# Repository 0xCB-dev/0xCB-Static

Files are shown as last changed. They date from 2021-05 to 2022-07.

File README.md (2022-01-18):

# 0xcb-static
## 40% with OLED and Encoder running QMK

Licence | OSHWA
:-------------------------:|:-------------------------:
 | (https://certification.oshwa.org/de000114.html)

#### Flashing

* `qmk clone`
* `cd qmk_firmware`
* `export LTO=Y`
* To go to bootloader hold the ESC key while plugging in (or RESET switch, then hold the BOOT switch, release RESET, release BOOT).
The board should now appear in lsusb (or device manager).
* `make 0xcb/static:via:flash`

### Assembly:

You can use the [humanpnp](https://files.0xcb.dev/0xCB-Static/humanpnp.html) to easily place components.

### PCB:
KiCad 6 stable

[Schematic](https://github.com/0xCB-dev/0xcb-static/blob/main/rev1.0/0xcb-static.pdf)

Top | Bottom
:-------------------------:|:-------------------------:
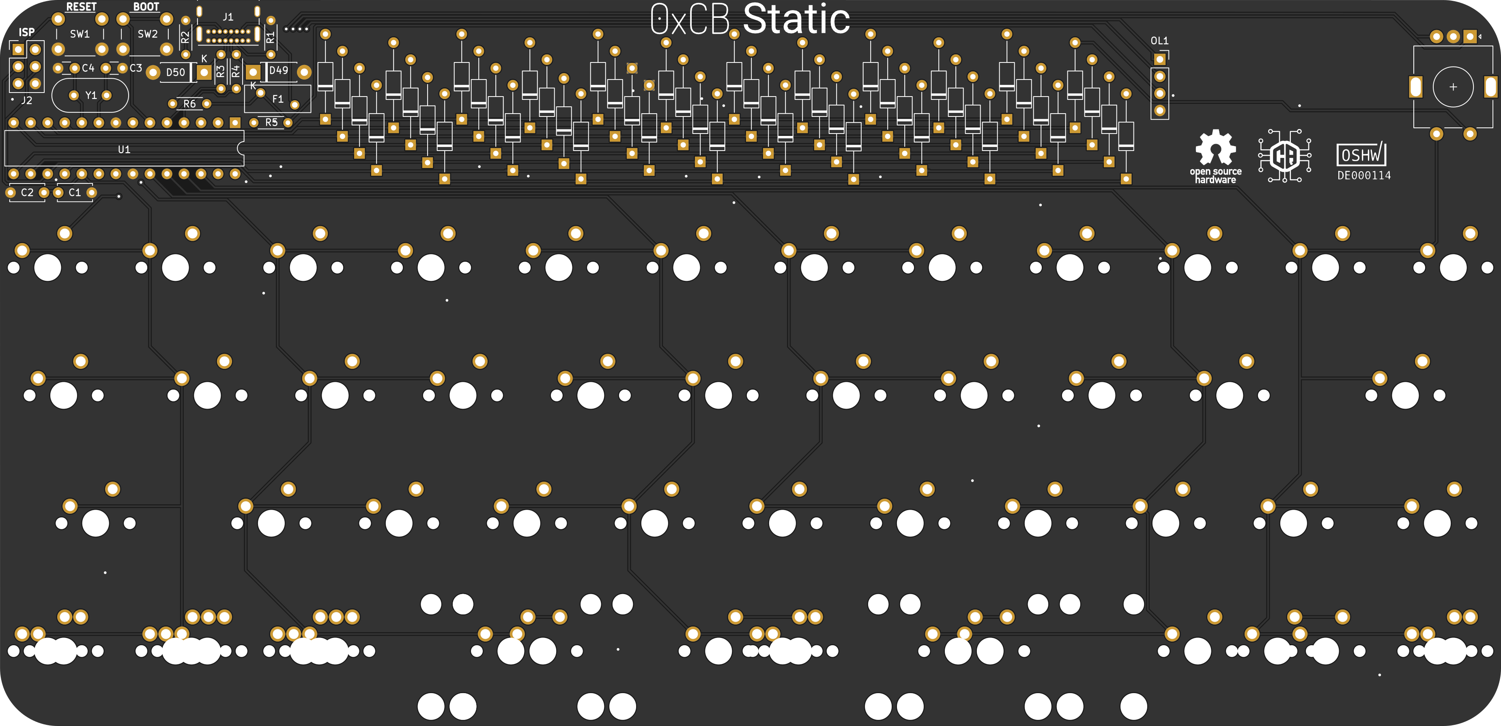
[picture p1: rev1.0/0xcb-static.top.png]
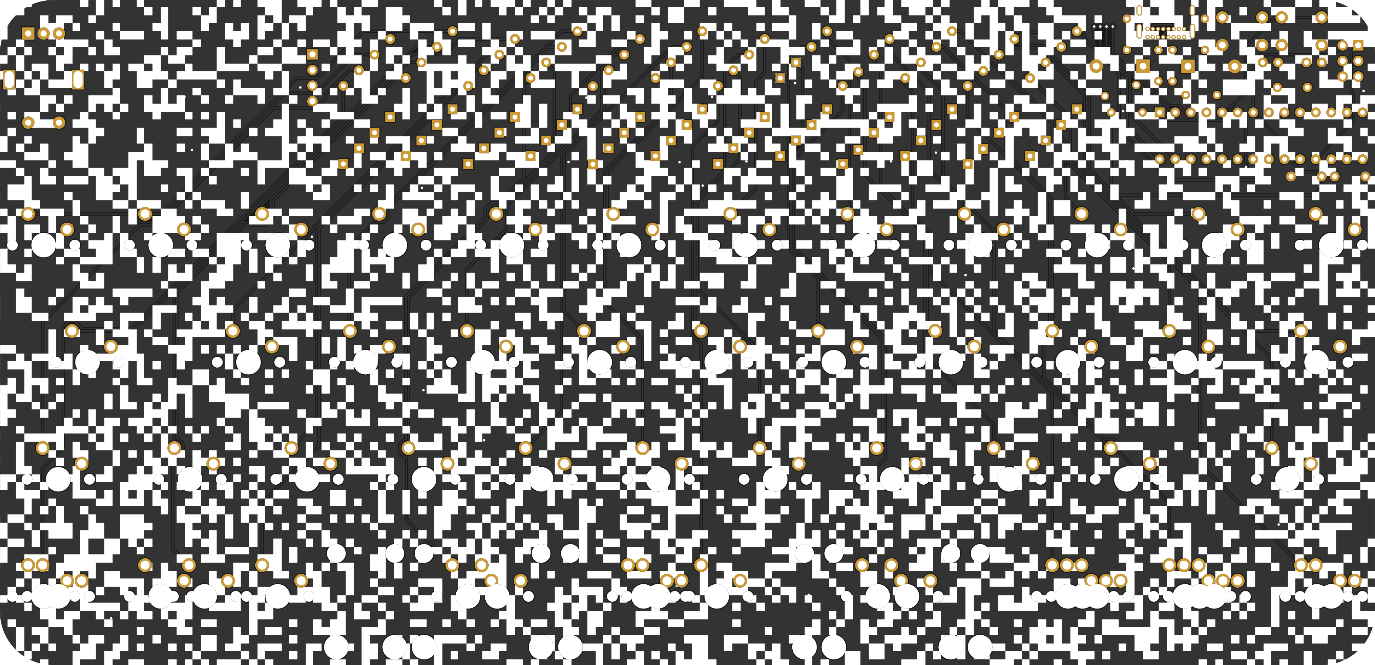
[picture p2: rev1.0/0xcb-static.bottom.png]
  |  

### 3D files:
[STLs](https://github.com/0xCB-dev/0xcb-static/tree/main/3D-files)

#### BOM:
| References | Value | Quantity |Part Nb. |
|---|---|---|---|
| C3, C4 | 20pF | 2 |C415398 |
| C1, C2 | 0.1uF | 2 |C409821 |
| R1, R2 | 5.1K | 2 |C58676 |
| R3, R4 | 75 | 2 |C713897 |
| R5 | 10k | 1 |C58673 |
| R6 | 1.5k | 1 |C433494 |
| D1, ..., D48 | 1N4148 | 48 |C14516 |
| D49, D50 | 1N4729 | 2 |C2532 |
| U1 | ATmega328-P | 1 |ATMEGA328P-PU-ND |
| Y1 | 16MHz | 1 |C16212 |
| F1 | 500mA | 1 |C268799 |
| SW1, SW2 | RESET, BOOT | 1 |450-1650-ND |
| MX1, ..., MX44 | MX-NoLED | 43 |Cherry MX switches |
| OL1 | OLED | 1 |SSD1306 128x32 |
| MX12 | EC11 | 1 |PEC11R-4220F-S0024-ND|
| J1 | USB4085 Type C | 1 |640-USB4085-GF-A |

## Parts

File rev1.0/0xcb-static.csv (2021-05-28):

Source: | /home/conor/Sites/0xcb-static/PCB/rev1.0/0xcb-static.kicad_sch
Date: | Fr 28 Mai 2021 11:54:58 CEST
Tool: | Eeschema (5.99.0-10540-g55c1d814f9)
Generator: | /usr/share/kicad-nightly/plugins/bom_csv_grouped_by_value.py
Component Count: | 111
Individual Components:
Item | Qty | Reference(s) | Value | LibPart | Footprint | Datasheet | Part Nb.
 |  | C1 | 0.1uF | Device:C_Small | Capacitor_THT:C_Disc_D5.0mm_W2.5mm_P5.00mm | ~ | C277965
 |  | C2 | 0.1uF | Device:C_Small | Capacitor_THT:C_Disc_D5.0mm_W2.5mm_P5.00mm | ~ | C277965
 |  | C3 | 20pF | Device:C_Small | Capacitor_THT:C_Disc_D3.0mm_W1.6mm_P2.50mm | ~ | C254096
 |  | C4 | 20pF | Device:C_Small | Capacitor_THT:C_Disc_D3.0mm_W1.6mm_P2.50mm | ~ | C254096
 |  | D1 | 1N4148 | Diode:1N4148 | Diode_THT:D_DO-35_SOD27_P12.70mm_Horizontal | https://assets.nexperia.com/documents/data-sheet/1N4148_1N4448.pdf | C14538
 |  | D2 | 1N4148 | Diode:1N4148 | Diode_THT:D_DO-35_SOD27_P12.70mm_Horizontal | https://assets.nexperia.com/documents/data-sheet/1N4148_1N4448.pdf | C14538
 |  | D3 | 1N4148 | Diode:1N4148 | Diode_THT:D_DO-35_SOD27_P12.70mm_Horizontal | https://assets.nexperia.com/documents/data-sheet/1N4148_1N4448.pdf | C14538
 |  | D4 | 1N4148 | Diode:1N4148 | Diode_THT:D_DO-35_SOD27_P12.70mm_Horizontal | https://assets.nexperia.com/documents/data-sheet/1N4148_1N4448.pdf | C14538
 |  | D5 | 1N4148 | Diode:1N4148 | Diode_THT:D_DO-35_SOD27_P12.70mm_Horizontal | https://assets.nexperia.com/documents/data-sheet/1N4148_1N4448.pdf | C14538
 |  | D6 | 1N4148 | Diode:1N4148 | Diode_THT:D_DO-35_SOD27_P12.70mm_Horizontal | https://assets.nexperia.com/documents/data-sheet/1N4148_1N4448.pdf | C14538
 |  | D7 | 1N4148 | Diode:1N4148 | Diode_THT:D_DO-35_SOD27_P12.70mm_Horizontal | https://assets.nexperia.com/documents/data-sheet/1N4148_1N4448.pdf | C14538
 |  | D8 | 1N4148 | Diode:1N4148 | Diode_THT:D_DO-35_SOD27_P12.70mm_Horizontal | https://assets.nexperia.com/documents/data-sheet/1N4148_1N4448.pdf | C14538
 |  | D9 | 1N4148 | Diode:1N4148 | Diode_THT:D_DO-35_SOD27_P12.70mm_Horizontal | https://assets.nexperia.com/documents/data-sheet/1N4148_1N4448.pdf | C14538
 |  | D10 | 1N4148 | Diode:1N4148 | Diode_THT:D_DO-35_SOD27_P12.70mm_Horizontal | https://assets.nexperia.com/documents/data-sheet/1N4148_1N4448.pdf | C14538
 |  | D11 | 1N4148 | Diode:1N4148 | Diode_THT:D_DO-35_SOD27_P12.70mm_Horizontal | https://assets.nexperia.com/documents/data-sheet/1N4148_1N4448.pdf | C14538
 |  | D12 | 1N4148 | Diode:1N4148 | Diode_THT:D_DO-35_SOD27_P12.70mm_Horizontal | https://assets.nexperia.com/documents/data-sheet/1N4148_1N4448.pdf | C14538
 |  | D13 | 1N4148 | Diode:1N4148 | Diode_THT:D_DO-35_SOD27_P12.70mm_Horizontal | https://assets.nexperia.com/documents/data-sheet/1N4148_1N4448.pdf | C14538
 |  | D14 | 1N4148 | Diode:1N4148 | Diode_THT:D_DO-35_SOD27_P12.70mm_Horizontal | https://assets.nexperia.com/documents/data-sheet/1N4148_1N4448.pdf | C14538
 |  | D15 | 1N4148 | Diode:1N4148 | Diode_THT:D_DO-35_SOD27_P12.70mm_Horizontal | https://assets.nexperia.com/documents/data-sheet/1N4148_1N4448.pdf | C14538
 |  | D16 | 1N4148 | Diode:1N4148 | Diode_THT:D_DO-35_SOD27_P12.70mm_Horizontal | https://assets.nexperia.com/documents/data-sheet/1N4148_1N4448.pdf | C14538
 |  | D17 | 1N4148 | Diode:1N4148 | Diode_THT:D_DO-35_SOD27_P12.70mm_Horizontal | https://assets.nexperia.com/documents/data-sheet/1N4148_1N4448.pdf | C14538
 |  | D18 | 1N4148 | Diode:1N4148 | Diode_THT:D_DO-35_SOD27_P12.70mm_Horizontal | https://assets.nexperia.com/documents/data-sheet/1N4148_1N4448.pdf | C14538
 |  | D19 | 1N4148 | Diode:1N4148 | Diode_THT:D_DO-35_SOD27_P12.70mm_Horizontal | https://assets.nexperia.com/documents/data-sheet/1N4148_1N4448.pdf | C14538
 |  | D20 | 1N4148 | Diode:1N4148 | Diode_THT:D_DO-35_SOD27_P12.70mm_Horizontal | https://assets.nexperia.com/documents/data-sheet/1N4148_1N4448.pdf | C14538
 |  | D21 | 1N4148 | Diode:1N4148 | Diode_THT:D_DO-35_SOD27_P12.70mm_Horizontal | https://assets.nexperia.com/documents/data-sheet/1N4148_1N4448.pdf | C14538
 |  | D22 | 1N4148 | Diode:1N4148 | Diode_THT:D_DO-35_SOD27_P12.70mm_Horizontal | https://assets.nexperia.com/documents/data-sheet/1N4148_1N4448.pdf | C14538
 |  | D23 | 1N4148 | Diode:1N4148 | Diode_THT:D_DO-35_SOD27_P12.70mm_Horizontal | https://assets.nexperia.com/documents/data-sheet/1N4148_1N4448.pdf | C14538
 |  | D24 | 1N4148 | Diode:1N4148 | Diode_THT:D_DO-35_SOD27_P12.70mm_Horizontal | https://assets.nexperia.com/documents/data-sheet/1N4148_1N4448.pdf | C14538
 |  | D25 | 1N4148 | Diode:1N4148 | Diode_THT:D_DO-35_SOD27_P12.70mm_Horizontal | https://assets.nexperia.com/documents/data-sheet/1N4148_1N4448.pdf | C14538
 |  | D26 | 1N4148 | Diode:1N4148 | Diode_THT:D_DO-35_SOD27_P12.70mm_Horizontal | https://assets.nexperia.com/documents/data-sheet/1N4148_1N4448.pdf | C14538
 |  | D27 | 1N4148 | Diode:1N4148 | Diode_THT:D_DO-35_SOD27_P12.70mm_Horizontal | https://assets.nexperia.com/documents/data-sheet/1N4148_1N4448.pdf | C14538
 |  | D28 | 1N4148 | Diode:1N4148 | Diode_THT:D_DO-35_SOD27_P12.70mm_Horizontal | https://assets.nexperia.com/documents/data-sheet/1N4148_1N4448.pdf | C14538
 |  | D29 | 1N4148 | Diode:1N4148 | Diode_THT:D_DO-35_SOD27_P12.70mm_Horizontal | https://assets.nexperia.com/documents/data-sheet/1N4148_1N4448.pdf | C14538
 |  | D30 | 1N4148 | Diode:1N4148 | Diode_THT:D_DO-35_SOD27_P12.70mm_Horizontal | https://assets.nexperia.com/documents/data-sheet/1N4148_1N4448.pdf | C14538
 |  | D31 | 1N4148 | Diode:1N4148 | Diode_THT:D_DO-35_SOD27_P12.70mm_Horizontal | https://assets.nexperia.com/documents/data-sheet/1N4148_1N4448.pdf | C14538
 |  | D32 | 1N4148 | Diode:1N4148 | Diode_THT:D_DO-35_SOD27_P12.70mm_Horizontal | https://assets.nexperia.com/documents/data-sheet/1N4148_1N4448.pdf | C14538
 |  | D33 | 1N4148 | Diode:1N4148 | Diode_THT:D_DO-35_SOD27_P12.70mm_Horizontal | https://assets.nexperia.com/documents/data-sheet/1N4148_1N4448.pdf | C14538
 |  | D34 | 1N4148 | Diode:1N4148 | Diode_THT:D_DO-35_SOD27_P12.70mm_Horizontal | https://assets.nexperia.com/documents/data-sheet/1N4148_1N4448.pdf | C14538
 |  | D35 | 1N4148 | Diode:1N4148 | Diode_THT:D_DO-35_SOD27_P12.70mm_Horizontal | https://assets.nexperia.com/documents/data-sheet/1N4148_1N4448.pdf | C14538
 |  | D36 | 1N4148 | Diode:1N4148 | Diode_THT:D_DO-35_SOD27_P12.70mm_Horizontal | https://assets.nexperia.com/documents/data-sheet/1N4148_1N4448.pdf | C14538
 |  | D37 | 1N4148 | Diode:1N4148 | Diode_THT:D_DO-35_SOD27_P12.70mm_Horizontal | https://assets.nexperia.com/documents/data-sheet/1N4148_1N4448.pdf | C14538
 |  | D38 | 1N4148 | Diode:1N4148 | Diode_THT:D_DO-35_SOD27_P12.70mm_Horizontal | https://assets.nexperia.com/documents/data-sheet/1N4148_1N4448.pdf | C14538
 |  | D39 | 1N4148 | Diode:1N4148 | Diode_THT:D_DO-35_SOD27_P12.70mm_Horizontal | https://assets.nexperia.com/documents/data-sheet/1N4148_1N4448.pdf | C14538
 |  | D40 | 1N4148 | Diode:1N4148 | Diode_THT:D_DO-35_SOD27_P12.70mm_Horizontal | https://assets.nexperia.com/documents/data-sheet/1N4148_1N4448.pdf | C14538
 |  | D41 | 1N4148 | Diode:1N4148 | Diode_THT:D_DO-35_SOD27_P12.70mm_Horizontal | https://assets.nexperia.com/documents/data-sheet/1N4148_1N4448.pdf | C14538
 |  | D42 | 1N4148 | Diode:1N4148 | Diode_THT:D_DO-35_SOD27_P12.70mm_Horizontal | https://assets.nexperia.com/documents/data-sheet/1N4148_1N4448.pdf | C14538
 |  | D43 | 1N4148 | Diode:1N4148 | Diode_THT:D_DO-35_SOD27_P12.70mm_Horizontal | https://assets.nexperia.com/documents/data-sheet/1N4148_1N4448.pdf | C14538
 |  | D44 | 1N4148 | Diode:1N4148 | Diode_THT:D_DO-35_SOD27_P12.70mm_Horizontal | https://assets.nexperia.com/documents/data-sheet/1N4148_1N4448.pdf | C14538
 |  | D45 | 1N4148 | Diode:1N4148 | Diode_THT:D_DO-35_SOD27_P12.70mm_Horizontal | https://assets.nexperia.com/documents/data-sheet/1N4148_1N4448.pdf | C14538
 |  | D46 | 1N4729 | Device:D_Schottky | Diode_THT:D_DO-41_SOD81_P7.62mm_Horizontal | ~ | C2532
 |  | D47 | 1N4729 | Device:D_Schottky | Diode_THT:D_DO-41_SOD81_P7.62mm_Horizontal | ~ | C2532
 |  | D48 | 1N4148 | Diode:1N4148 | Diode_THT:D_DO-35_SOD27_P12.70mm_Horizontal | https://assets.nexperia.com/documents/data-sheet/1N4148_1N4448.pdf | C14538
 |  | D49 | 1N4148 | Diode:1N4148 | Diode_THT:D_DO-35_SOD27_P12.70mm_Horizontal | https://assets.nexperia.com/documents/data-sheet/1N4148_1N4448.pdf | C14538
 |  | D50 | 1N4148 | Diode:1N4148 | Diode_THT:D_DO-35_SOD27_P12.70mm_Horizontal | https://assets.nexperia.com/documents/data-sheet/1N4148_1N4448.pdf | C14538
 |  | F1 | 500mA | Device:Polyfuse_Small | Fuse:Fuse_BelFuse_0ZRE0025FF_L9.6mm_W3.8mm | ~ | C268799
 |  | J1 | USB_C_Receptacle_USB2.0 | Connector:USB_C_Receptacle_USB2.0 | Connector_USB:USB_C_Receptacle_GCT_USB4085 | https://www.usb.org/sites/default/files/documents/usb_type-c.zip | 2073-USB4085-GF-ACT-ND
 |  | MX1 | MX-NoLED | static:MX-NoLED | MX_Only:MXOnly-1U-NoLED |  | amz
 |  | MX2 | MX-NoLED | static:MX-NoLED | MX_Only:MXOnly-1U-NoLED |  | amz
 |  | MX3 | MX-NoLED | static:MX-NoLED | MX_Only:MXOnly-1U-NoLED |  | amz
 |  | MX4 | MX-NoLED | static:MX-NoLED | MX_Only:MXOnly-1U-NoLED |  | amz
 |  | MX5 | MX-NoLED | static:MX-NoLED | MX_Only:MXOnly-1U-NoLED |  | amz
 |  | MX6 | MX-NoLED | static:MX-NoLED | MX_Only:MXOnly-1U-NoLED |  | amz
 |  | MX7 | MX-NoLED | static:MX-NoLED | MX_Only:MXOnly-1U-NoLED |  | amz
 |  | MX8 | MX-NoLED | static:MX-NoLED | MX_Only:MXOnly-1U-NoLED |  | amz
 |  | MX9 | MX-NoLED | static:MX-NoLED | MX_Only:MXOnly-1U-NoLED |  | amz
 |  | MX10 | MX-NoLED | static:MX-NoLED | MX_Only:MXOnly-1U-NoLED |  | amz
 |  | MX11 | MX-NoLED | static:MX-NoLED | MX_Only:MXOnly-1U-NoLED |  | amz
 |  | MX12 | EC11 | Device:RotaryEncoder_Switch | Rotary_Encoder:RotaryEncoder_Alps_EC11E-Switch_Vertical_H20mm | ~ | amz
 |  | MX13 | MX-NoLED | static:MX-NoLED | MX_Only:MXOnly-1.25U-NoLED |  | amz
 |  | MX14 | MX-NoLED | static:MX-NoLED | MX_Only:MXOnly-1U-NoLED |  | amz
 |  | MX15 | MX-NoLED | static:MX-NoLED | MX_Only:MXOnly-1U-NoLED |  | amz
 |  | MX16 | MX-NoLED | static:MX-NoLED | MX_Only:MXOnly-1U-NoLED |  | amz
 |  | MX17 | MX-NoLED | static:MX-NoLED | MX_Only:MXOnly-1U-NoLED |  | amz
 |  | MX18 | MX-NoLED | static:MX-NoLED | MX_Only:MXOnly-1U-NoLED |  | amz
 |  | MX19 | MX-NoLED | static:MX-NoLED | MX_Only:MXOnly-1U-NoLED |  | amz
 |  | MX20 | MX-NoLED | static:MX-NoLED | MX_Only:MXOnly-1U-NoLED |  | amz
 |  | MX21 | MX-NoLED | static:MX-NoLED | MX_Only:MXOnly-1U-NoLED |  | amz
 |  | MX22 | MX-NoLED | static:MX-NoLED | MX_Only:MXOnly-1U-NoLED |  | amz
 |  | MX23 | MX-NoLED | static:MX-NoLED | MX_Only:MXOnly-1.75U-NoLED |  | amz
 |  | MX24 | MX-NoLED | static:MX-NoLED | MX_Only:MXOnly-1U-NoLED |  | amz
 |  | MX25 | MX-NoLED | static:MX-NoLED | MX_Only:MXOnly-1.75U-NoLED |  | amz
 |  | MX26 | MX-NoLED | static:MX-NoLED | MX_Only:MXOnly-1U-NoLED |  | amz
 |  | MX27 | MX-NoLED | static:MX-NoLED | MX_Only:MXOnly-1U-NoLED |  | amz
 |  | MX28 | MX-NoLED | static:MX-NoLED | MX_Only:MXOnly-1U-NoLED |  | amz
 |  | MX29 | MX-NoLED | static:MX-NoLED | MX_Only:MXOnly-1U-NoLED |  | amz
 |  | MX30 | MX-NoLED | static:MX-NoLED | MX_Only:MXOnly-1U-NoLED |  | amz
 |  | MX31 | MX-NoLED | static:MX-NoLED | MX_Only:MXOnly-1U-NoLED |  | amz
 |  | MX32 | MX-NoLED | static:MX-NoLED | MX_Only:MXOnly-1U-NoLED |  | amz
 |  | MX33 | MX-NoLED | static:MX-NoLED | MX_Only:MXOnly-1U-NoLED |  | amz
 |  | MX34 | MX-NoLED | static:MX-NoLED | MX_Only:MXOnly-1U-NoLED |  | amz
 |  | MX35 | MX-NoLED | static:MX-NoLED | MX_Only:MXOnly-1.25U-NoLED |  | amz
 |  | MX36 | MX-NoLED | static:MX-NoLED | MX_Only:MXOnly-1U-NoLED |  | amz
 |  | MX37 | MX-NoLED | static:MX-NoLED | MX_Only:MXOnly-1U-NoLED |  | amz
 |  | MX38 | MX-NoLED | static:MX-NoLED | MX_Only:MXOnly-1U-NoLED |  | amz
 |  | MX39 | MX-NoLED | static:MX-NoLED | MX_Only:MXOnly-2.75U-NoLED |  | amz
 |  | MX40 | MX-NoLED | static:MX-NoLED | MX_Only:MXOnly-1U-NoLED |  | amz
 |  | MX41 | MX-NoLED | static:MX-NoLED | MX_Only:MXOnly-2.25U-NoLED |  | amz
 |  | MX42 | MX-NoLED | static:MX-NoLED | MX_Only:MXOnly-1U-NoLED |  | amz
 |  | MX43 | MX-NoLED | static:MX-NoLED | MX_Only:MXOnly-1U-NoLED |  | amz
 |  | MX44 | MX-NoLED | static:MX-NoLED | MX_Only:MXOnly-1U-NoLED |  | amz
 |  | OL1 | OLED | static:OLED | Connector_PinSocket_2.54mm:PinSocket_1x04_P2.54mm_Vertical |  | amz
 |  | R1 | 5.1K | Device:R | Resistor_THT:R_Axial_DIN0204_L3.6mm_D1.6mm_P5.08mm_Horizontal | ~ | C58676
 |  | R2 | 5.1K | Device:R | Resistor_THT:R_Axial_DIN0204_L3.6mm_D1.6mm_P5.08mm_Horizontal | ~ | C58676
 |  | R3 | 75 | Device:R | Resistor_THT:R_Axial_DIN0204_L3.6mm_D1.6mm_P5.08mm_Horizontal | ~ | C713897
 |  | R4 | 75 | Device:R | Resistor_THT:R_Axial_DIN0204_L3.6mm_D1.6mm_P5.08mm_Horizontal | ~ | C713897
 |  | R5 | 10k | Device:R | Resistor_THT:R_Axial_DIN0204_L3.6mm_D1.6mm_P5.08mm_Horizontal | ~ | C58673
 |  | R6 | 1.5k | Device:R | Resistor_THT:R_Axial_DIN0204_L3.6mm_D1.6mm_P5.08mm_Horizontal | ~ | C433494
 |  | SW1 | RESET | Switch:SW_Push | Button_Switch_THT:SW_PUSH_6mm_H5mm | ~ | C127509
 |  | SW2 | BOOT | Switch:SW_Push | Button_Switch_THT:SW_PUSH_6mm_H5mm | ~ | C127509
 |  | U1 | ATmega328-P | MCU_Microchip_ATmega:ATmega328-P | Package_DIP:DIP-28_W7.62mm | http://ww1.microchip.com/downloads/en/DeviceDoc/ATmega328_P%20AVR%20MCU%20with%20picoPower%20Technology%20Data%20Sheet%2040001984A.pdf | C613508
 |  | Y1 | 16MHz | Device:Crystal | Crystal:Crystal_HC49-4H_Vertical | ~ | C16212
Collated Components:
Item | Qty | Reference(s) | Value | LibPart | Footprint | Datasheet | Part Nb.
1 | 2 | C1, C2 | 0.1uF | Device:C_Small | Capacitor_THT:C_Disc_D5.0mm_W2.5mm_P5.00mm | ~ | C277965
2 | 2 | C3, C4 | 20pF | Device:C_Small | Capacitor_THT:C_Disc_D3.0mm_W1.6mm_P2.50mm | ~ | C254096
3 | 48 | D1, D2, D3, D4, D5, D6, D7, D8, D9, D10, D11, D12, D13, D14, D15, D16, D17, D18, D19, D20, D21, D22, D23, D24, D25, D26, D27, D28, D29, D30, D31, D32, D33, D34, D35, D36, D37, D38, D39, D40, D41, D42, D43, D44, D45, D48, D49, D50 | 1N4148 | Diode:1N4148 | Diode_THT:D_DO-35_SOD27_P12.70mm_Horizontal | https://assets.nexperia.com/documents/data-sheet/1N4148_1N4448.pdf | C14538
4 | 2 | D46, D47 | 1N4729 | Device:D_Schottky | Diode_THT:D_DO-41_SOD81_P7.62mm_Horizontal | ~ | C2532
5 | 1 | F1 | 500mA | Device:Polyfuse_Small | Fuse:Fuse_BelFuse_0ZRE0025FF_L9.6mm_W3.8mm | ~ | C268799
6 | 1 | J1 | USB_C_Receptacle_USB2.0 | Connector:USB_C_Receptacle_USB2.0 | Connector_USB:USB_C_Receptacle_GCT_USB4085 | https://www.usb.org/sites/default/files/documents/usb_type-c.zip | 2073-USB4085-GF-ACT-ND
7 | 37 | MX1, MX2, MX3, MX4, MX5, MX6, MX7, MX8, MX9, MX10, MX11, MX14, MX15, MX16, MX17, MX18, MX19, MX20, MX21, MX22, MX24, MX26, MX27, MX28, MX29, MX30, MX31, MX32, MX33, MX34, MX36, MX37, MX38, MX40, MX42, MX43, MX44 | MX-NoLED | static:MX-NoLED | MX_Only:MXOnly-1U-NoLED |  | amz
8 | 1 | MX12 | EC11 | Device:RotaryEncoder_Switch | Rotary_Encoder:RotaryEncoder_Alps_EC11E-Switch_Vertical_H20mm | ~ | amz
9 | 2 | MX13, MX35 | MX-NoLED | static:MX-NoLED | MX_Only:MXOnly-1.25U-NoLED |  | amz
10 | 2 | MX23, MX25 | MX-NoLED | static:MX-NoLED | MX_Only:MXOnly-1.75U-NoLED |  | amz
11 | 1 | MX39 | MX-NoLED | static:MX-NoLED | MX_Only:MXOnly-2.75U-NoLED |  | amz
12 | 1 | MX41 | MX-NoLED | static:MX-NoLED | MX_Only:MXOnly-2.25U-NoLED |  | amz
13 | 1 | OL1 | OLED | static:OLED | Connector_PinSocket_2.54mm:PinSocket_1x04_P2.54mm_Vertical |  | amz
14 | 2 | R1, R2 | 5.1K | Device:R | Resistor_THT:R_Axial_DIN0204_L3.6mm_D1.6mm_P5.08mm_Horizontal | ~ | C58676
15 | 2 | R3, R4 | 75 | Device:R | Resistor_THT:R_Axial_DIN0204_L3.6mm_D1.6mm_P5.08mm_Horizontal | ~ | C713897
16 | 1 | R5 | 10k | Device:R | Resistor_THT:R_Axial_DIN0204_L3.6mm_D1.6mm_P5.08mm_Horizontal | ~ | C58673
17 | 1 | R6 | 1.5k | Device:R | Resistor_THT:R_Axial_DIN0204_L3.6mm_D1.6mm_P5.08mm_Horizontal | ~ | C433494
18 | 1 | SW1 | RESET | Switch:SW_Push | Button_Switch_THT:SW_PUSH_6mm_H5mm | ~ | C127509
19 | 1 | SW2 | BOOT | Switch:SW_Push | Button_Switch_THT:SW_PUSH_6mm_H5mm | ~ | C127509
20 | 1 | U1 | ATmega328-P | MCU_Microchip_ATmega:ATmega328-P | Package_DIP:DIP-28_W7.62mm | http://ww1.microchip.com/downloads/en/DeviceDoc/ATmega328_P%20AVR%20MCU%20with%20picoPower%20Technology%20Data%20Sheet%2040001984A.pdf | C613508
21 | 1 | Y1 | 16MHz | Device:Crystal | Crystal:Crystal_HC49-4H_Vertical | ~ | C16212

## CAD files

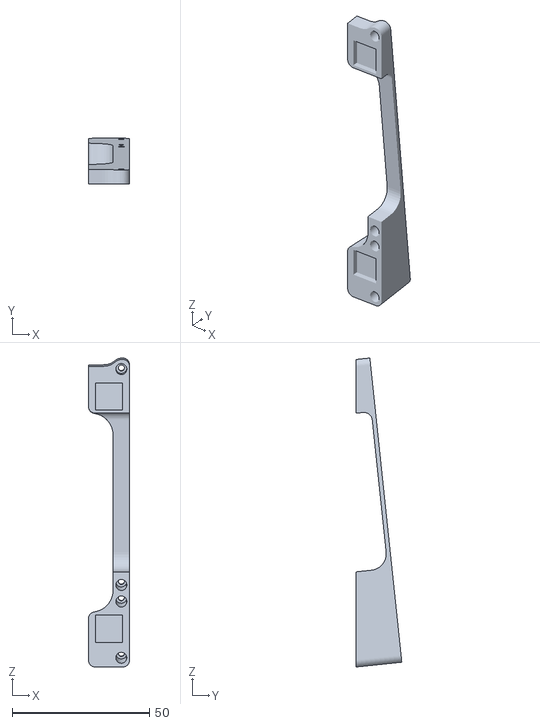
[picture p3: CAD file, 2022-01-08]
3D-files/Feet Right.STL
15.0 x 16.7 x 112.6

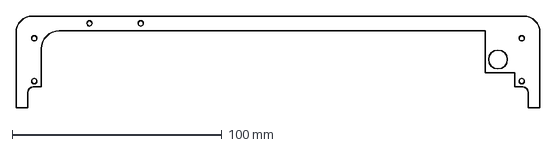
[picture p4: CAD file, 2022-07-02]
acrylic-case/Plate6.DXF
250.0 x 43.9 mm

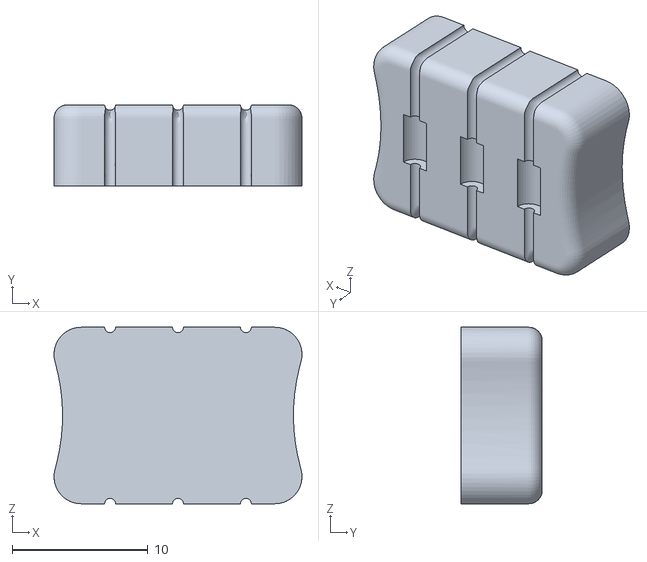
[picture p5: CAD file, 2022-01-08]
3D-files/BenderEnder.STL
18.3 x 6.00 x 13.0

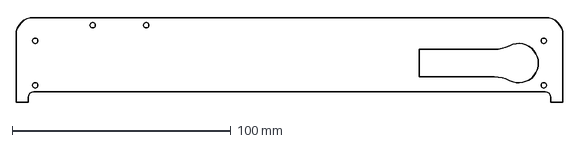
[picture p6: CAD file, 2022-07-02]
acrylic-case/Plate7.DXF
250.0 x 38.9 mm

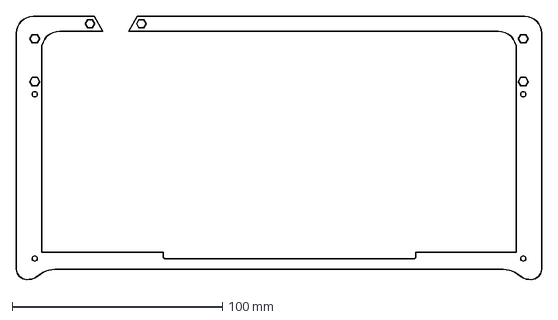
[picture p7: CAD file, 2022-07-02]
acrylic-case/Plate4.DXF
250.0 x 125.2 mm

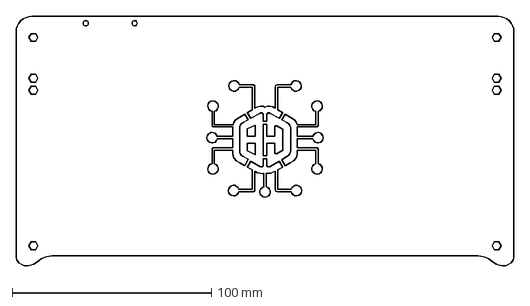
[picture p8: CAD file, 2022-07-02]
acrylic-case/Plate1.DXF
250.0 x 125.2 mm

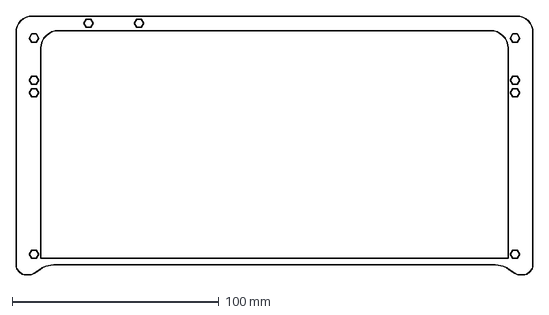
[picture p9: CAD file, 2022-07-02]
acrylic-case/Plate2.DXF
250.0 x 125.2 mm

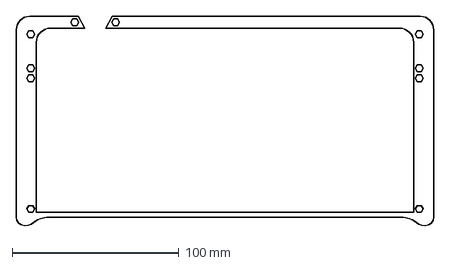
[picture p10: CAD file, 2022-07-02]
acrylic-case/Plate3.DXF
250.0 x 125.2 mm

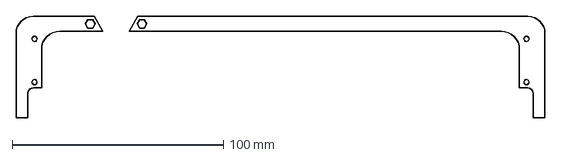
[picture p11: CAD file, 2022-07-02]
acrylic-case/Plate5.DXF
250.0 x 47.9 mm

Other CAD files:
3D-files/Feet Left.STL

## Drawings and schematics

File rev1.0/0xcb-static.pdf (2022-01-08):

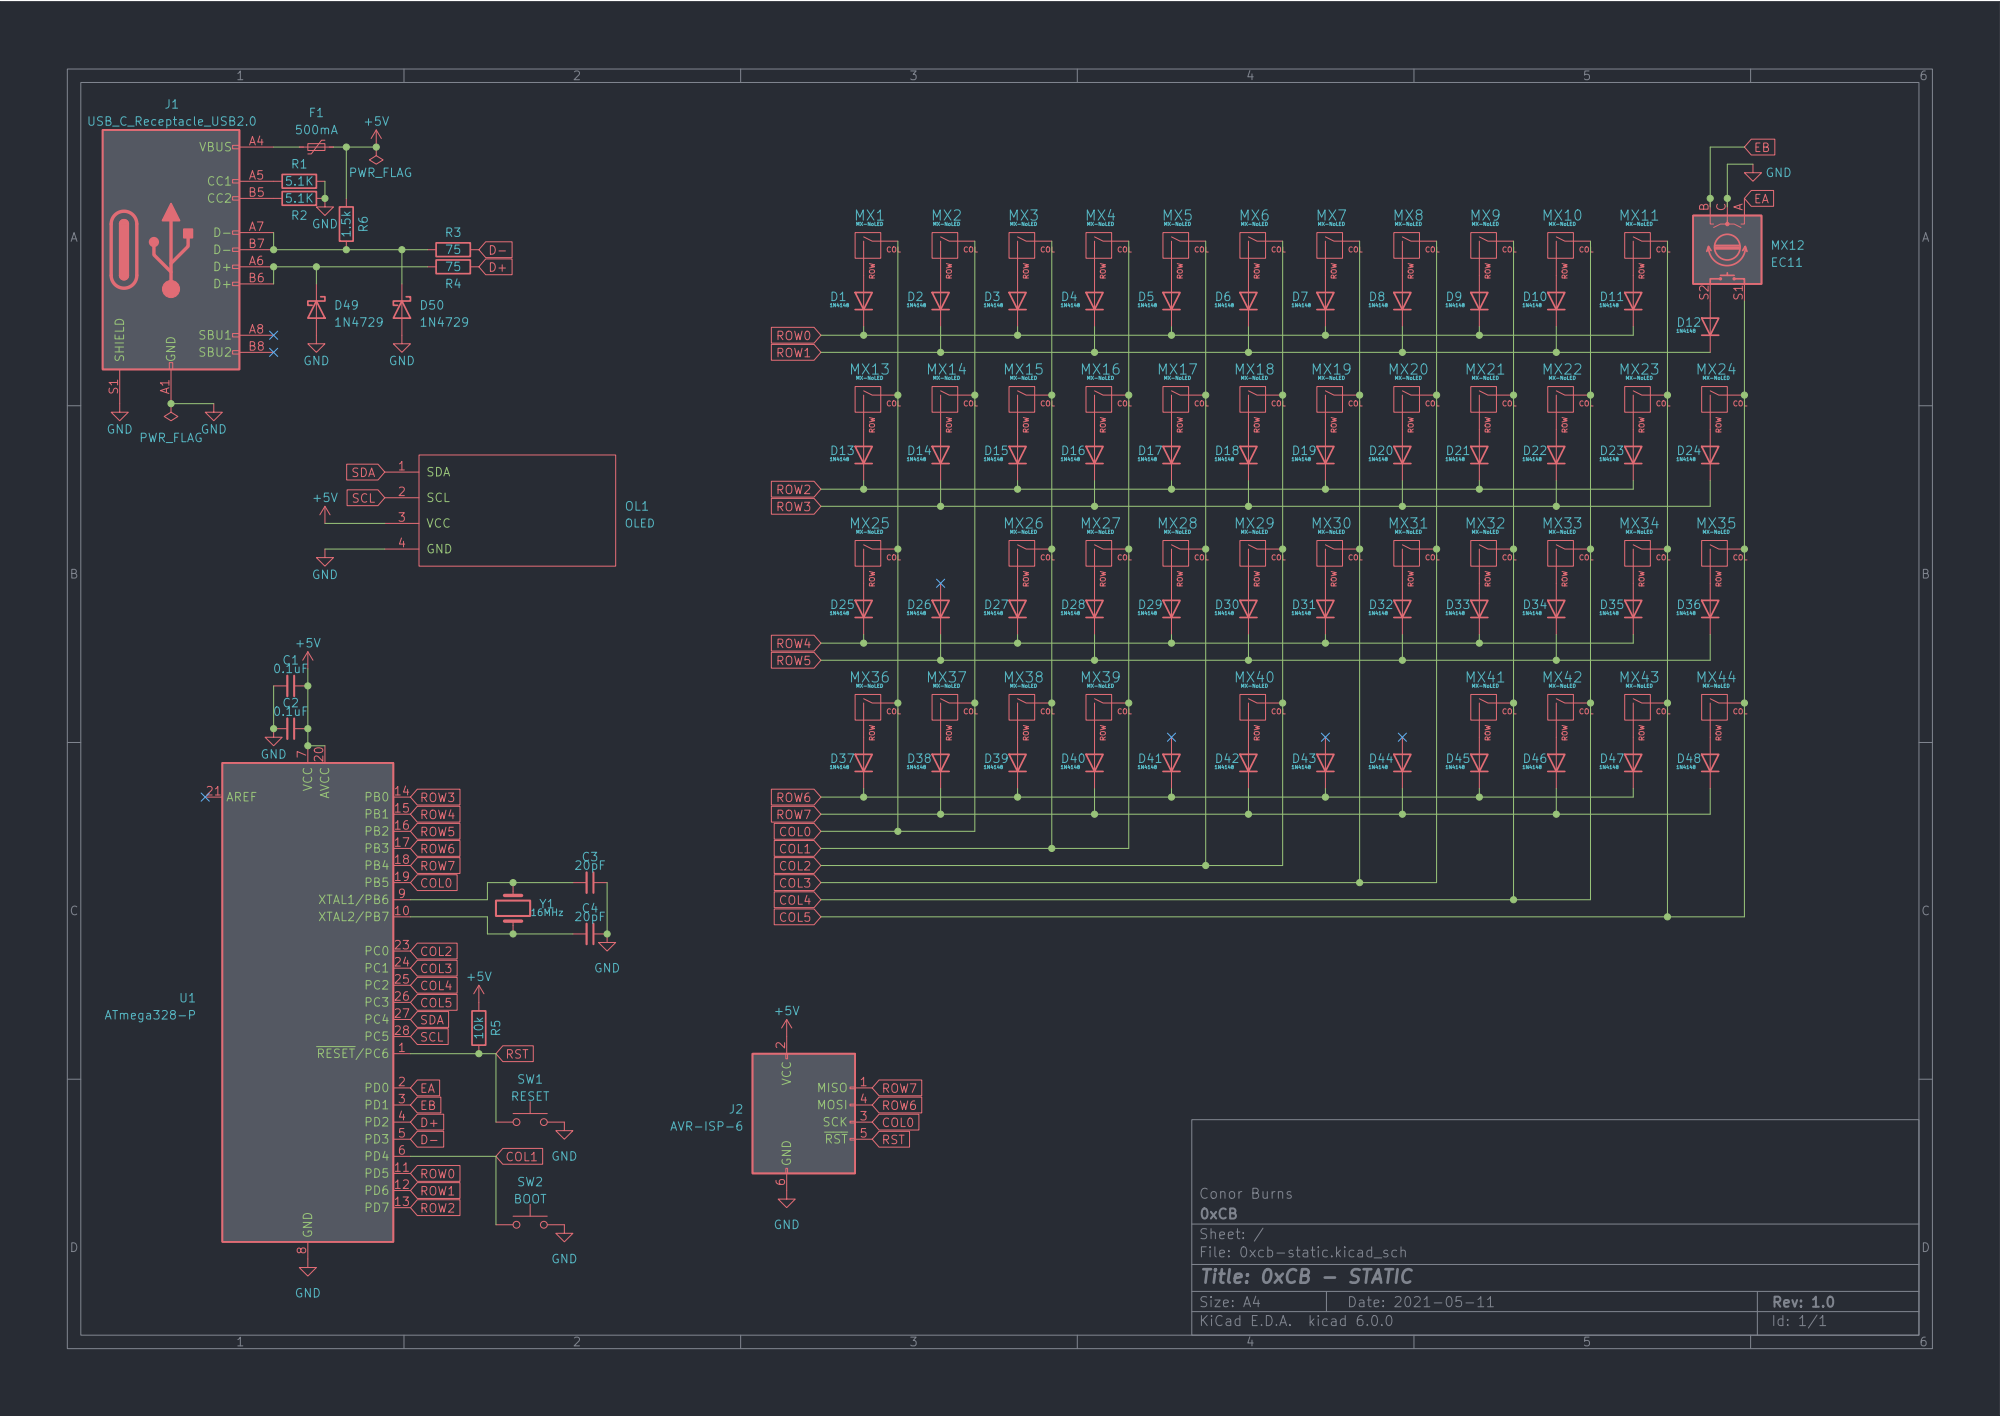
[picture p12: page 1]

COL ROW MX42 MX-NoLED GND R2

COL ROW MX41 MX-NoLED R6 1.5k

1N4148 COL ROW MX2 MX-NoLED D1

1N4148 COL ROW MX8 MX-NoLED D8

COL ROW MX13 MX-NoLED D25

COL ROW MX21 MX-NoLED D49

COL ROW MX27 MX-NoLED COL ROW MX26 MX-NoLED PWR_FLAG

COL ROW MX44 MX-NoLED D22

1N4148 COL ROW MX28 MX-NoLED D29

1N4148 COL ROW MX34 MX-NoLED D35

1N4148 COL ROW MX40 MX-NoLED D40

COL ROW MX43 MX-NoLED D47

2 SCK 3 MOSI 4 ~{RST} 5 GND

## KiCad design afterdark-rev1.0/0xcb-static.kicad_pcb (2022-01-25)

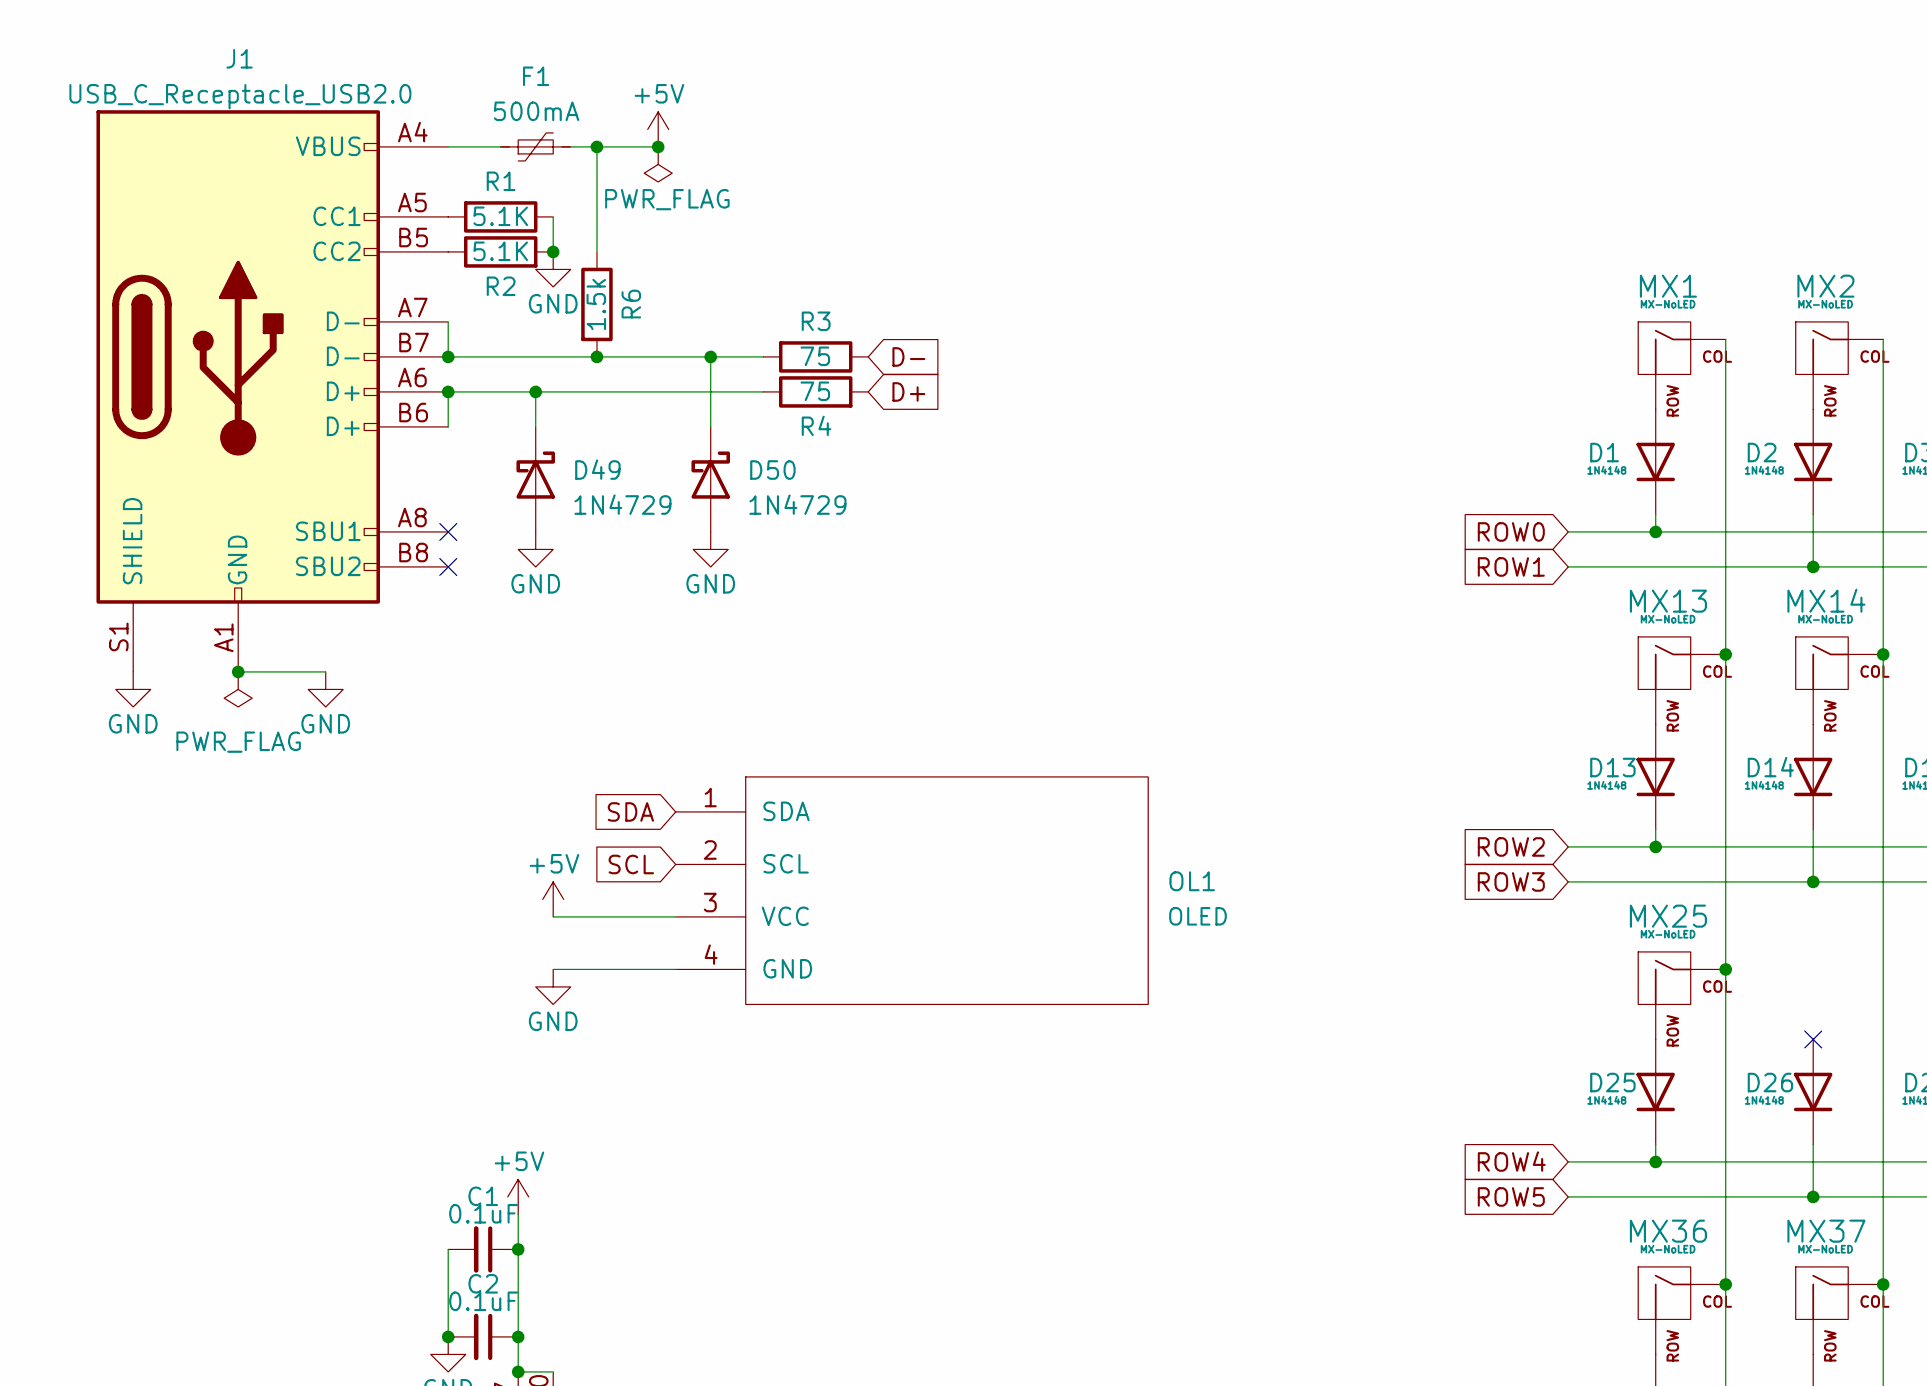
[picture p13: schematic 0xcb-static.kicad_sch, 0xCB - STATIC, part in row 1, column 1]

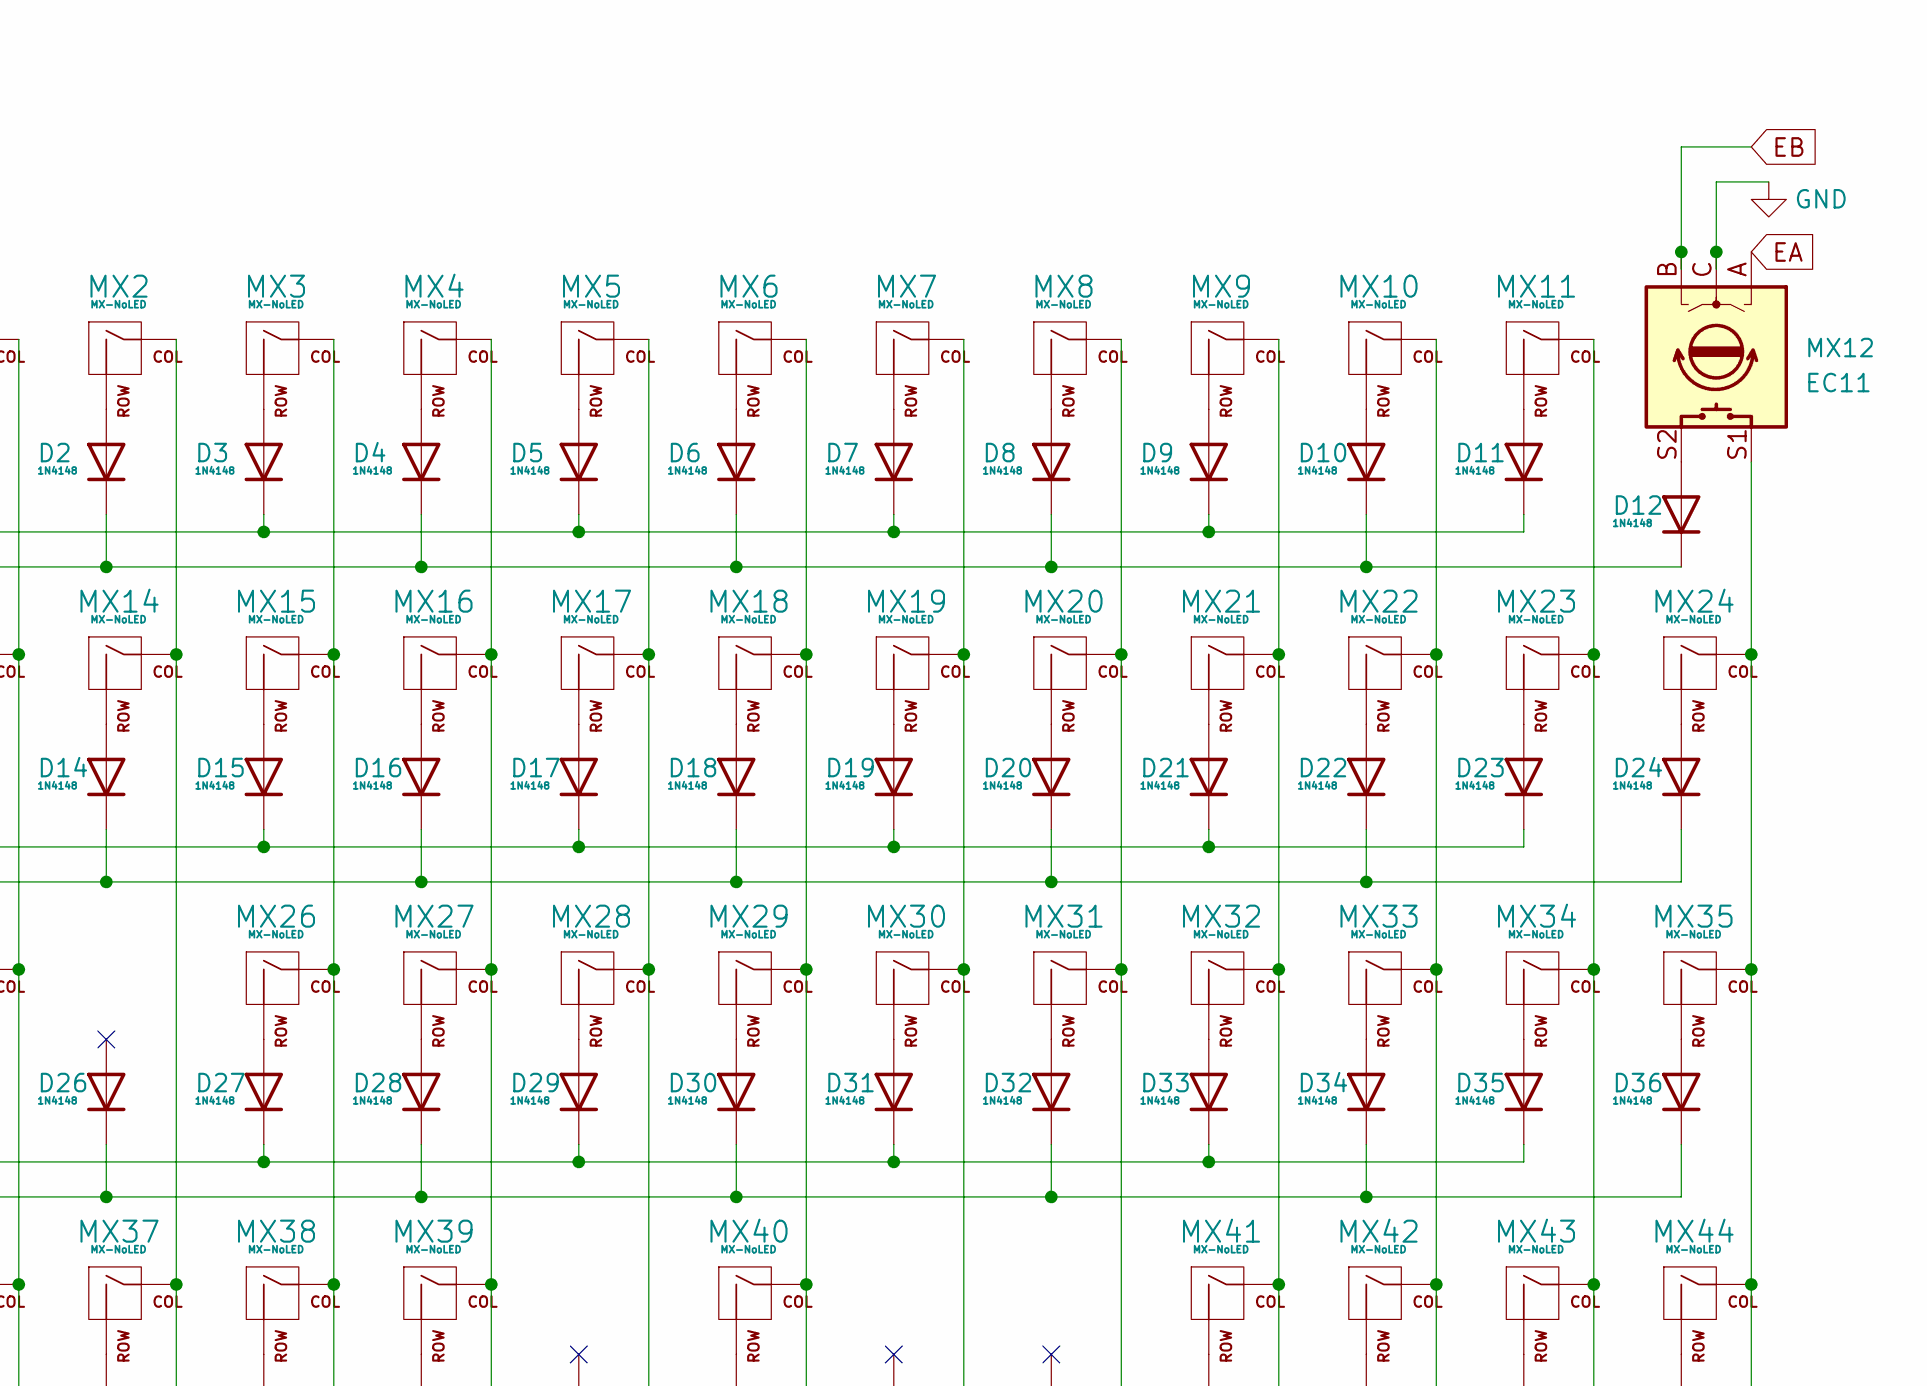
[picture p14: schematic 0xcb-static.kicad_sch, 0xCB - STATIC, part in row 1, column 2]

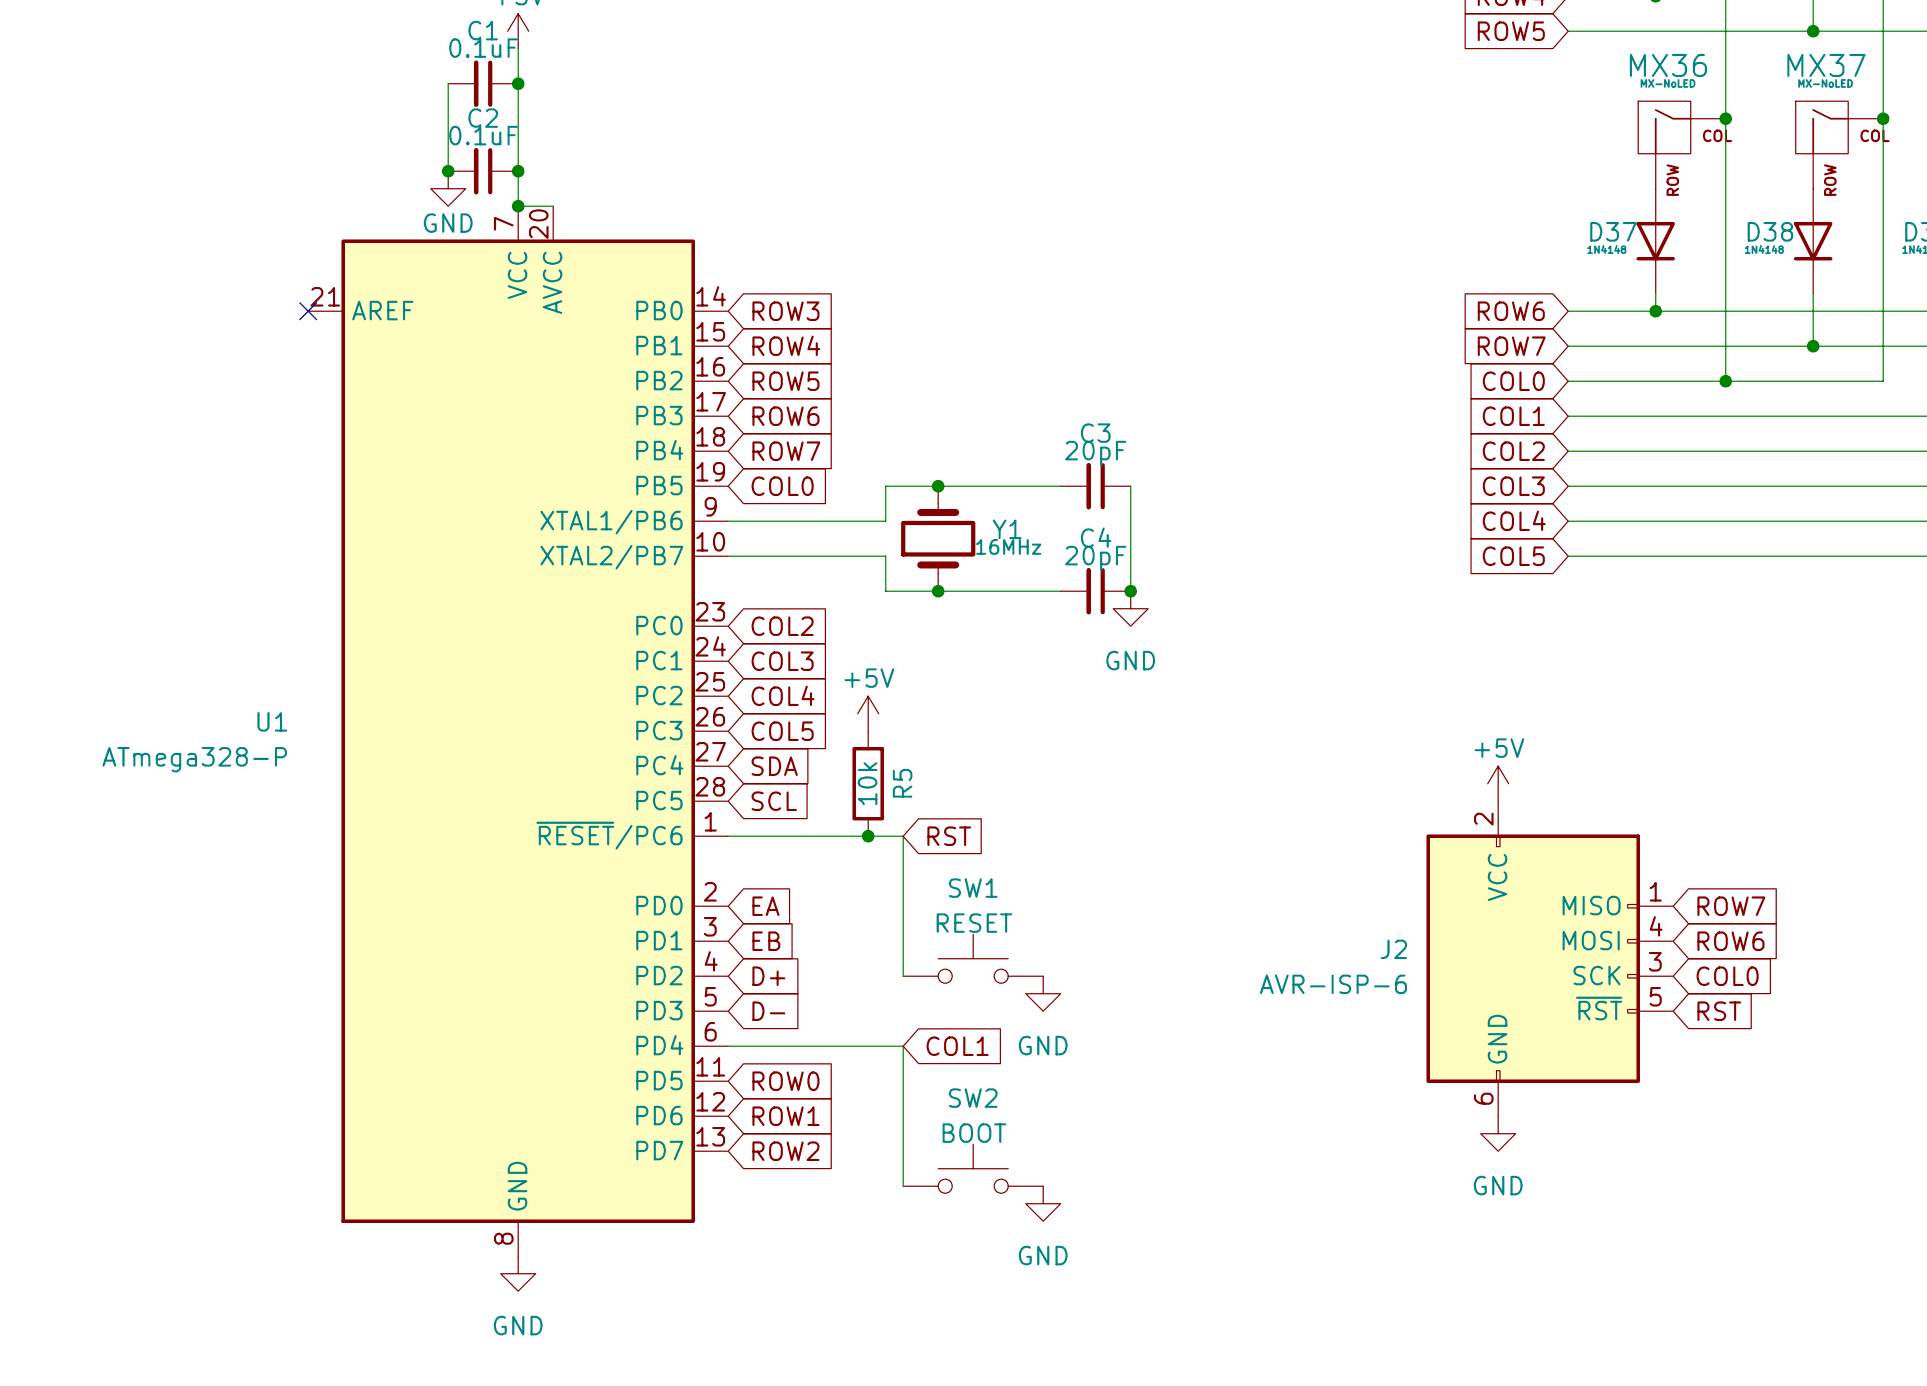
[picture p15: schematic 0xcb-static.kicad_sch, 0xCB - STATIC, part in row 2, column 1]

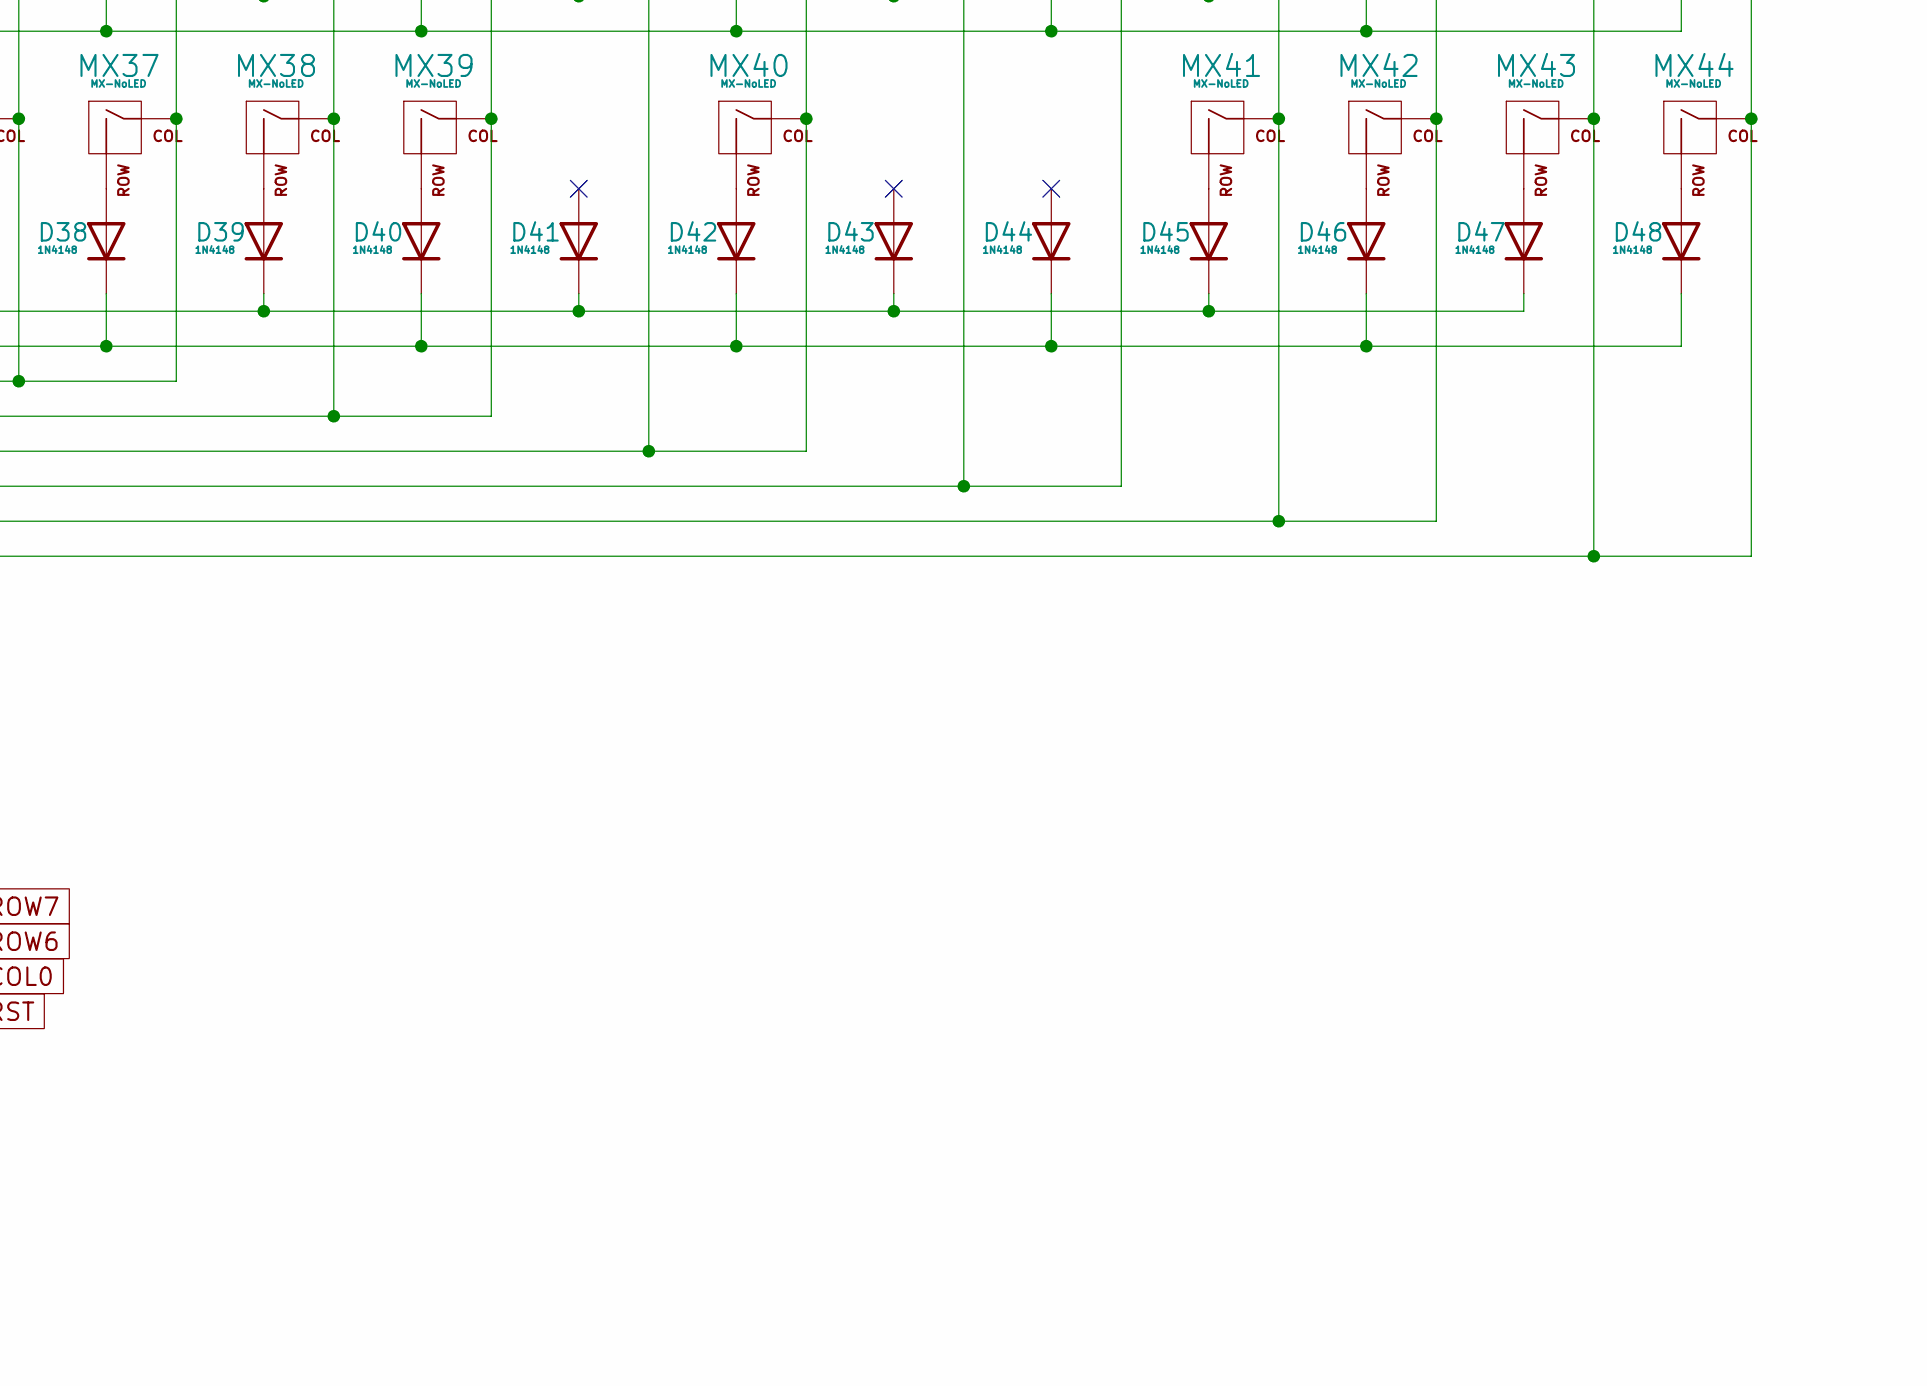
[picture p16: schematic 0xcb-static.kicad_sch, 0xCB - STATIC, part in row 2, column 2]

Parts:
C1, C2: 0.1uF; C_Disc_D5.0mm_W2.5mm_P5.00mm; Part Nb. C277965
C3, C4: 20pF; C_Disc_D3.0mm_W1.6mm_P2.50mm; Part Nb. C254096
D1, D2, D3, D4, D5, D6, D7, D8, D9, D10, D11, D12, D13, D14, D15, D16, D17, D18, D19, D20, D21, D22, D23, D24, D25, D26, D27, D28, D29, D30, D31, D32, D33, D34, D35, D36, D37, D38, D39, D40, D41, D42, D43, D44, D45, D46, D47, D48: 1N4148; D_DO-35_SOD27_P12.70mm_Horizontal; Part Nb. C14538
D49, D50: 1N4729; D_DO-41_SOD81_P7.62mm_Horizontal; Part Nb. C2532
F1: 500mA; Fuse_BelFuse_0ZRE0025FF_L9.6mm_W3.8mm; Part Nb. C268799
J1: USB_C_Receptacle_USB2.0; USB_C_Receptacle_GCT_USB4085; Part Nb. 2073-USB4085-GF-ACT-ND
J2: AVR-ISP-6; PinHeader_2x03_P2.54mm_Vertical
MX1, MX2, MX3, MX4, MX5, MX6, MX7, MX8, MX9, MX10, MX11, MX14, MX15, MX16, MX17, MX18, MX19, MX20, MX21, MX22, MX24, MX26, MX27, MX28, MX29, MX30, MX31, MX32, MX33, MX34, MX36, MX37, MX38, MX40, MX42, MX43, MX44: MX-NoLED; MXOnly-1U-NoLED; Part Nb. amz
MX12: EC11; RotaryEncoder_Alps_EC11E-Switch_Vertical_H20mm; Part Nb. amz
MX13, MX35: MX-NoLED; MXOnly-1.25U-NoLED; Part Nb. amz
MX23, MX25: MX-NoLED; MXOnly-1.75U-NoLED; Part Nb. amz
MX39: MX-NoLED; MXOnly-2.75U-NoLED; Part Nb. amz
MX41: MX-NoLED; MXOnly-2.25U-NoLED; Part Nb. amz
OL1: OLED; PinSocket_1x04_P2.54mm_Vertical; Part Nb. amz
R1, R2: 5.1K; R_Axial_DIN0204_L3.6mm_D1.6mm_P5.08mm_Horizontal; Part Nb. C58676
R3, R4: 75; R_Axial_DIN0204_L3.6mm_D1.6mm_P5.08mm_Horizontal; Part Nb. C713897
R5: 10k; R_Axial_DIN0204_L3.6mm_D1.6mm_P5.08mm_Horizontal; Part Nb. C58673
R6: 1.5k; R_Axial_DIN0204_L3.6mm_D1.6mm_P5.08mm_Horizontal; Part Nb. C433494
SW1: RESET; SW_PUSH_6mm_H5mm; Part Nb. C127509
SW2: BOOT; SW_PUSH_6mm_H5mm; Part Nb. C127509
U1: ATmega328-P; DIP-28_W7.62mm; Part Nb. C613508
Y1: 16MHz; Crystal_HC49-4H_Vertical; Part Nb. C16212

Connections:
+5V: C1.1, C2.1, F1.2, J2.2 (VCC), OL1.3 (VCC), R5.2, R6.1, U1.7 (VCC), U1.20 (AVCC)
COL0: J2.3 (SCK), MX1.1 (COL), MX2.1 (COL), MX13.1 (COL), MX14.1 (COL), MX25.1 (COL), MX36.1 (COL), MX37.1 (COL), U1.19 (PB5); also elsewhere on the board
COL1: MX3.1 (COL), MX4.1 (COL), MX15.1 (COL), MX16.1 (COL), MX26.1 (COL), MX27.1 (COL), MX38.1 (COL), MX39.1 (COL), SW2.1, U1.6 (PD4); also elsewhere on the board
COL2: MX5.1 (COL), MX6.1 (COL), MX17.1 (COL), MX18.1 (COL), MX28.1 (COL), MX29.1 (COL), MX40.1 (COL), U1.23 (PC0); also elsewhere on the board
COL3: MX7.1 (COL), MX8.1 (COL), MX19.1 (COL), MX20.1 (COL), MX30.1 (COL), MX31.1 (COL), U1.24 (PC1)
COL4: MX9.1 (COL), MX10.1 (COL), MX21.1 (COL), MX22.1 (COL), MX32.1 (COL), MX33.1 (COL), MX41.1 (COL), MX42.1 (COL), U1.25 (PC2); also elsewhere on the board
COL5: MX11.1 (COL), MX12.S1, MX23.1 (COL), MX24.1 (COL), MX34.1 (COL), MX35.1 (COL), MX43.1 (COL), MX44.1 (COL), U1.26 (PC3); also elsewhere on the board
D+: R4.2, U1.4 (PD2)
D-: R3.1, U1.5 (PD3)
EA: MX12.A, U1.2 (PD0)
EB: MX12.B, U1.3 (PD1)
GND: C1.2, C2.2, C3.1, C4.1, D49.2 (A), D50.2 (A), J1.A1 (GND), J1.A12 (GND), J1.B1 (GND), J1.B12 (GND), J1.S1 (SHIELD), J2.6 (GND), MX12.C, OL1.4 (GND), R1.1, R2.2, SW1.2, SW2.2, U1.8 (GND), U1.22 (GND)
unnamed: C3.2, U1.9 (XTAL1/PB6), Y1.2
unnamed: C4.2, U1.10 (XTAL2/PB7), Y1.1
unnamed: D1.2 (A), MX1.2 (ROW)
unnamed: D2.2 (A), MX2.2 (ROW)
unnamed: D3.2 (A), MX3.2 (ROW)
unnamed: D4.2 (A), MX4.2 (ROW)
unnamed: D5.2 (A), MX5.2 (ROW)
unnamed: D6.2 (A), MX6.2 (ROW)
unnamed: D7.2 (A), MX7.2 (ROW)
unnamed: D8.2 (A), MX8.2 (ROW)
unnamed: D9.2 (A), MX9.2 (ROW)
unnamed: D10.2 (A), MX10.2 (ROW)
unnamed: D11.2 (A), MX11.2 (ROW)
unnamed: D12.2 (A), MX12.S2
unnamed: D13.2 (A), MX13.2 (ROW)
unnamed: D14.2 (A), MX14.2 (ROW)
unnamed: D15.2 (A), MX15.2 (ROW)
unnamed: D16.2 (A), MX16.2 (ROW)
unnamed: D17.2 (A), MX17.2 (ROW)
unnamed: D18.2 (A), MX18.2 (ROW)
unnamed: D19.2 (A), MX19.2 (ROW)
unnamed: D20.2 (A), MX20.2 (ROW)
unnamed: D21.2 (A), MX21.2 (ROW)
unnamed: D22.2 (A), MX22.2 (ROW)
unnamed: D23.2 (A), MX23.2 (ROW)
unnamed: D24.2 (A), MX24.2 (ROW)
unnamed: D25.2 (A), MX25.2 (ROW)
unnamed: D27.2 (A), MX26.2 (ROW)
unnamed: D28.2 (A), MX27.2 (ROW)
unnamed: D29.2 (A), MX28.2 (ROW)
unnamed: D30.2 (A), MX29.2 (ROW)
unnamed: D31.2 (A), MX30.2 (ROW)
unnamed: D32.2 (A), MX31.2 (ROW)
unnamed: D33.2 (A), MX32.2 (ROW)
unnamed: D34.2 (A), MX33.2 (ROW)
unnamed: D35.2 (A), MX34.2 (ROW)
unnamed: D36.2 (A), MX35.2 (ROW)
unnamed 49: D37.2 (A), MX36.2 (ROW); also elsewhere on the board
unnamed 50: D38.2 (A), MX37.2 (ROW); also elsewhere on the board
unnamed 51: D39.2 (A), MX38.2 (ROW); also elsewhere on the board
unnamed 52: D40.2 (A), MX39.2 (ROW); also elsewhere on the board
unnamed 54: D42.2 (A), MX40.2 (ROW); also elsewhere on the board
unnamed: D45.2 (A), MX41.2 (ROW)
unnamed: D46.2 (A), MX42.2 (ROW)
unnamed 57: D47.2 (A), MX43.2 (ROW); also elsewhere on the board
unnamed 58: D48.2 (A), MX44.2 (ROW); also elsewhere on the board
unnamed: D49.1 (K), J1.A6 (D+), J1.B6 (D+), R4.1
unnamed: D50.1 (K), J1.A7 (D-), J1.B7 (D-), R3.2, R6.2
unnamed: F1.1, J1.A4 (VBUS), J1.A9 (VBUS), J1.B4 (VBUS), J1.B9 (VBUS)
unnamed: J1.A5 (CC1), R1.2
unnamed: J1.B5 (CC2), R2.1
ROW0: D1.1 (K), D3.1 (K), D5.1 (K), D7.1 (K), D9.1 (K), D11.1 (K), U1.11 (PD5)
ROW1: D2.1 (K), D4.1 (K), D6.1 (K), D8.1 (K), D10.1 (K), D12.1 (K), U1.12 (PD6)
ROW2: D13.1 (K), D15.1 (K), D17.1 (K), D19.1 (K), D21.1 (K), D23.1 (K), U1.13 (PD7)
ROW3: D14.1 (K), D16.1 (K), D18.1 (K), D20.1 (K), D22.1 (K), D24.1 (K), U1.14 (PB0)
ROW4: D25.1 (K), D27.1 (K), D29.1 (K), D31.1 (K), D33.1 (K), D35.1 (K), U1.15 (PB1)
ROW5: D26.1 (K), D28.1 (K), D30.1 (K), D32.1 (K), D34.1 (K), D36.1 (K), U1.16 (PB2)
ROW6: D37.1 (K), D39.1 (K), D41.1 (K), D43.1 (K), D45.1 (K), D47.1 (K), J2.4 (MOSI), U1.17 (PB3)
ROW7: D38.1 (K), D40.1 (K), D42.1 (K), D44.1 (K), D46.1 (K), D48.1 (K), J2.1 (MISO), U1.18 (PB4)
RST: J2.5 (~RST), R5.1, SW1.1, U1.1 (~RESET~/PC6)
SCL: OL1.2 (SCL), U1.28 (PC5)
SDA: OL1.1 (SDA), U1.27 (PC4)

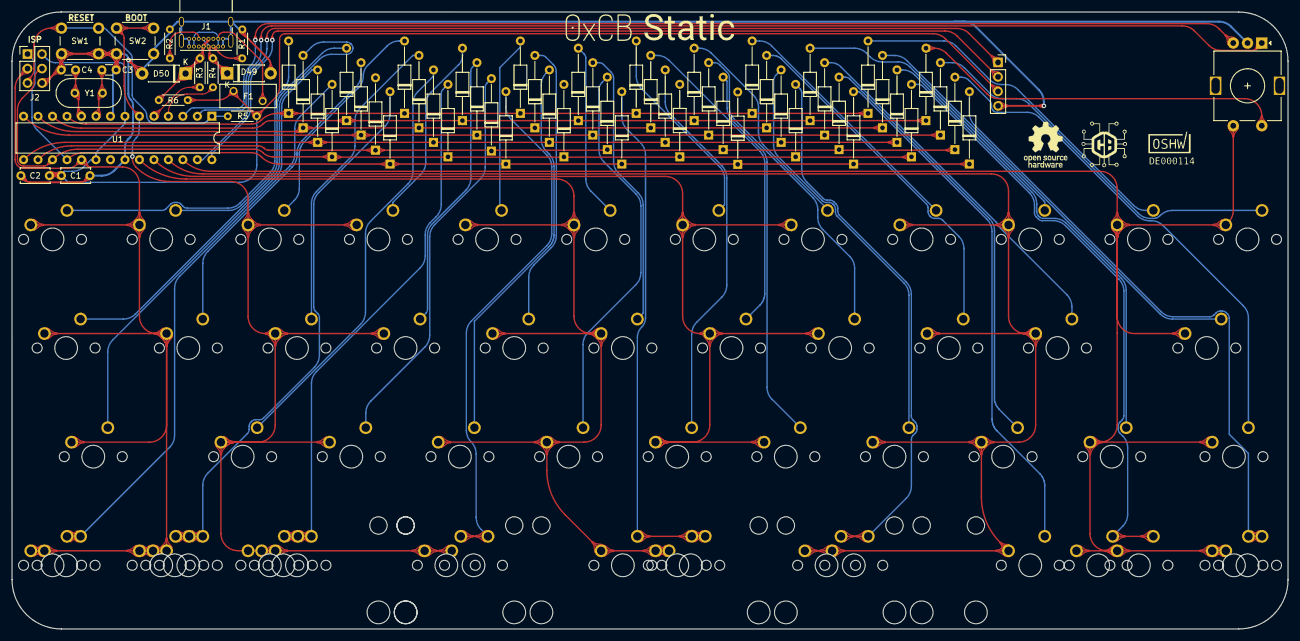
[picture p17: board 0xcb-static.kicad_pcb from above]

Board: 2 copper layers, 223.8 x 108.2 mm, 127 parts (0 on the bottom side), 74 nets.

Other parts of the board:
L1: font1; svg2mod
L2: font2; svg2mod
L3: OSHW-Logo_7.5x8mm_SilkScreen
L4: LOGO; logo
MX36_1, MX37_1, MX38_1, MX43_1, MX44_1: MX-NoLED; MXOnly-1.25U-NoLED
MX37_2, MX38_2, MX40_1: MX-NoLED; MXOnly-1U-NoLED
MX39_1: MX-NoLED; MXOnly-2.25U-NoLED
MX40_2: 6.25U; MXOnly-6.25U-NoLED
MX41_1: MX-NoLED; MXOnly-2.75U-NoLED

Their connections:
COL0: MX36_1.1 (COL), MX37_1.1 (COL), MX37_2.1 (COL); also elsewhere on the board
COL1: MX38_1.1 (COL), MX38_2.1 (COL), MX39_1.1 (COL); also elsewhere on the board
COL2: MX40_1.1 (COL), MX40_2.1; also elsewhere on the board
COL4: MX41_1.1 (COL); also elsewhere on the board
COL5: MX43_1.1 (COL), MX44_1.1 (COL); also elsewhere on the board
unnamed 49: MX36_1.2 (ROW); also elsewhere on the board
unnamed 50: MX37_1.2 (ROW), MX37_2.2 (ROW); also elsewhere on the board
unnamed 51: MX38_1.2 (ROW), MX38_2.2 (ROW); also elsewhere on the board
unnamed 52: MX39_1.2 (ROW); also elsewhere on the board
unnamed 54: MX40_1.2 (ROW), MX40_2.2; also elsewhere on the board
unnamed 57: MX43_1.2 (ROW); also elsewhere on the board
unnamed 58: MX44_1.2 (ROW); also elsewhere on the board

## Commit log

2021-05-10 added submodules
    [0xcb-static.kicad_pcb, 0xcb-static.kicad_sch]
2021-05-28 added v1
    [0xcb-static.csv, 0xcb-static.kicad_pcb, 0xcb-static.kicad_sch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]
2021-05-30 updated bom
2021-06-26 updated prod files
    [0xcb-static-B_Cu.gbr, 0xcb-static-B_Mask.gbr, 0xcb-static-B_Paste.gbr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]
2021-06-26 updated readme bom
2022-01-25 made a version for use with afterdark with rounded traces and no ground plane
    [0xcb-static.kicad_pcb, 0xcb-static.kicad_sch]
2022-07-02 removed case sensitive files for windows ._.
2022-07-02 added acrylic case files
    [Plate1.DXF, Plate2.DXF, Plate3.DXF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]
